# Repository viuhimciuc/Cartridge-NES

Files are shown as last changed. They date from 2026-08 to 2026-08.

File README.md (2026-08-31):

# 🎮 Nintendo Entertainment System (NES) Cartridge PCBs






An open-source collection of hardware design files and schematics for custom, functional **Nintendo Entertainment System (NES)** cartridge printed circuit boards (PCBs), using the [SST39SF010A](https://www.microchip.com/en-us/product/sst39sf010a), [SST39SF020A](https://www.microchip.com/en-us/product/sst39sf020a), [SST39SF040](https://www.microchip.com/en-us/product/sst39sf040) memory chip. This repository includes boards based on original discrete logic designs, advanced memory management controllers (MMCs), and mask ROM replacement utilities created inside **KiCad**.

---

## 📂 Repository Structure

The project organizes board designs by memory mapper architectures and utility profiles:

*   **📁 `Discrete logic boards using`** – Simple mapper solutions utilizing standard 74-series logic chips (e.g., AxROM, UxROM, NROM configurations).
*   **📁 `MMC1 boards NES-SxROM`** – Designs compatible with the Nintendo **MMC1** ASIC mapper family supporting multi-directional scrolling and battery-backed saves.
*   **📁 `MMC3 boards NES-TxROM`** – Performance configurations adapting the highly versatile **MMC3** ASIC architecture for scanline IRQ counters and larger ROM sizes.
*   **📁 `NES MASK ROM`** – Hardware breakout and adapter boards targeting pin-compatible conversions from modern Flash/EPROM/EEPROM chips to original NES hardware slots.
*   **📊 Documentation Assets:**
    *   `Mappers.xls` – Comparison matrices tracking hardware compatibility, signaling, and line configurations.
    *   `pin_MMC3.xls` – Precision mapping registers and Pinout details targeting the MMC3 layout.

---

## 📸 PCB Gallery

<p align="center">
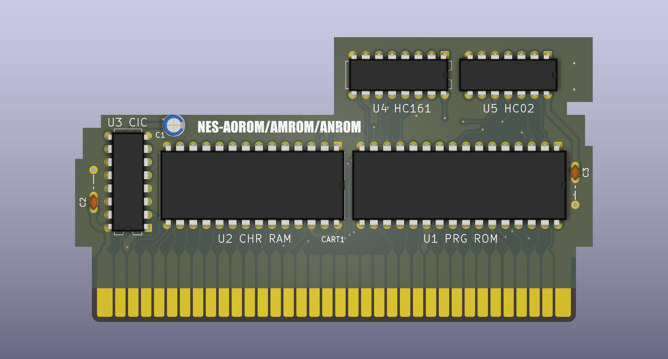
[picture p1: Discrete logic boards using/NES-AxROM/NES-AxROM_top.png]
AxROM
  
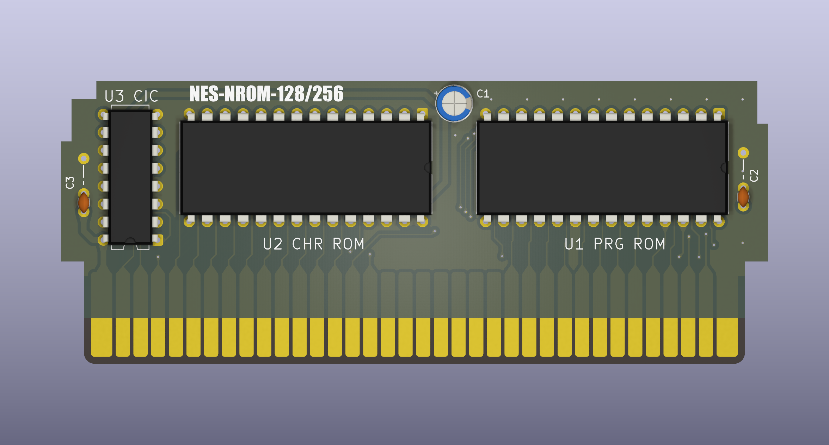
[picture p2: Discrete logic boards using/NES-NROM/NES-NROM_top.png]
NROM
  
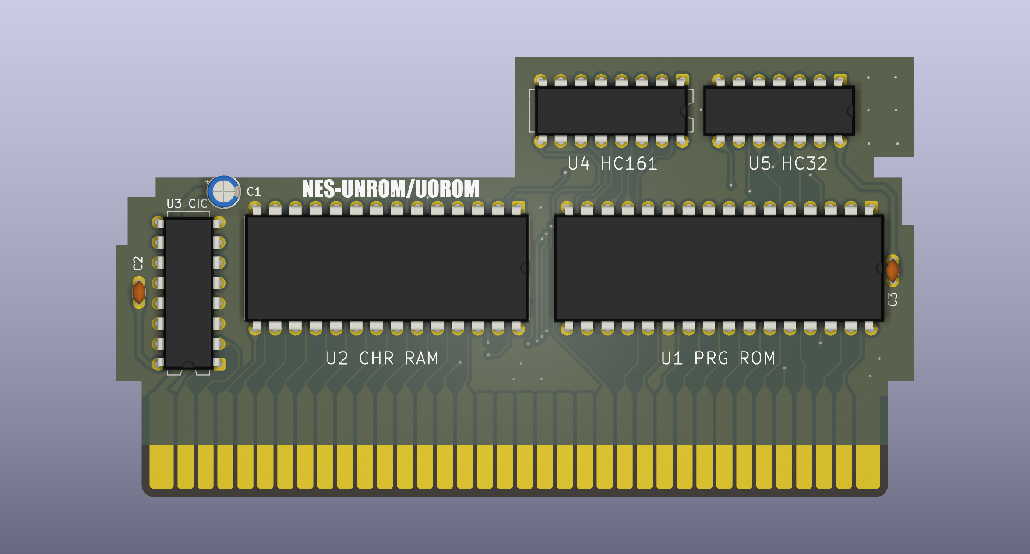
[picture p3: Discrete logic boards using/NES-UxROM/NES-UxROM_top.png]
UxROM
  
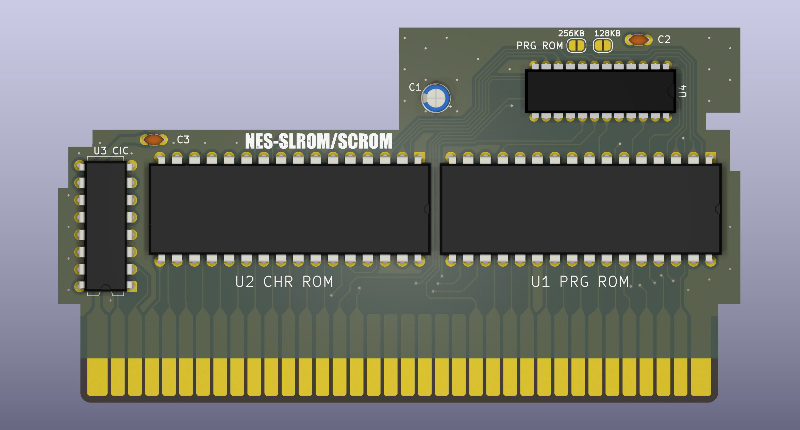
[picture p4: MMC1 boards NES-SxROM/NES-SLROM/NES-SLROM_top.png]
MMC1 SLROM Board
  
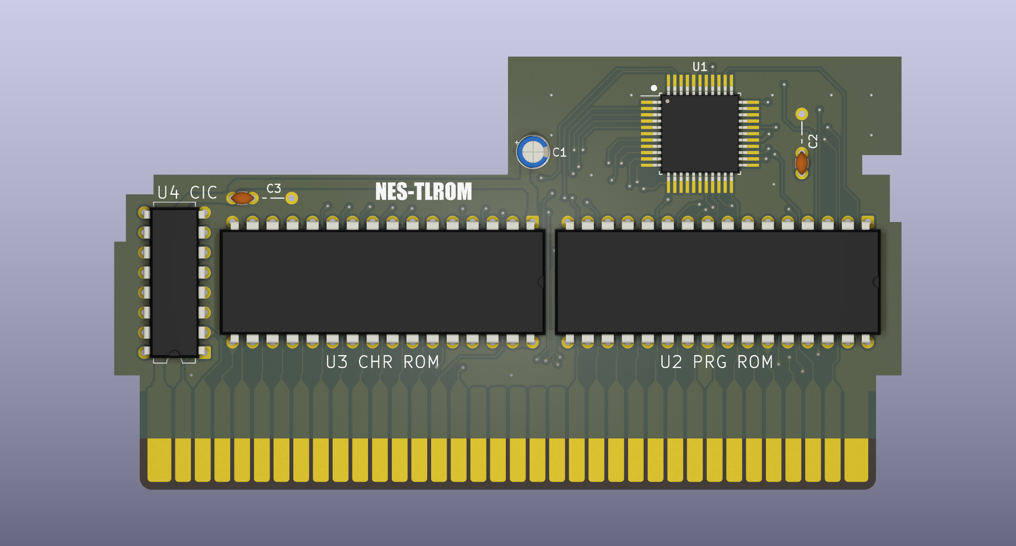
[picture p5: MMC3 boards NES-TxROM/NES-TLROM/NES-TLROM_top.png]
MMC3 TLROM Board
  
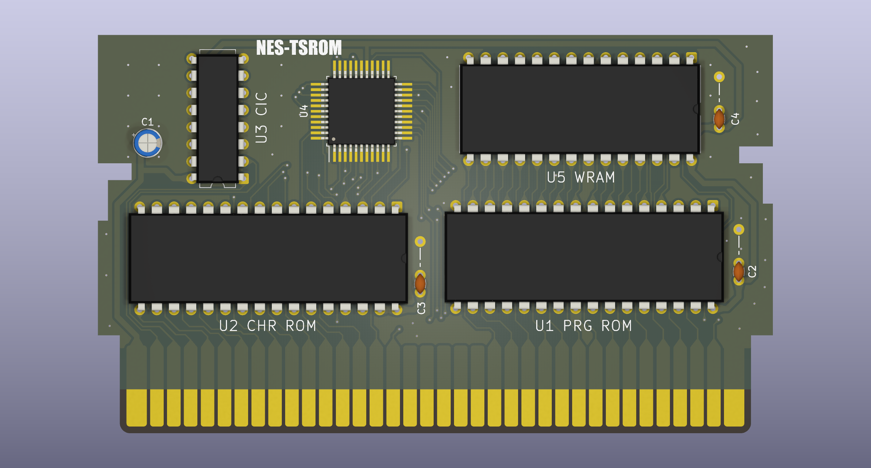
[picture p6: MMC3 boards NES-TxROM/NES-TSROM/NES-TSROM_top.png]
MMC3 TSROM Board
  
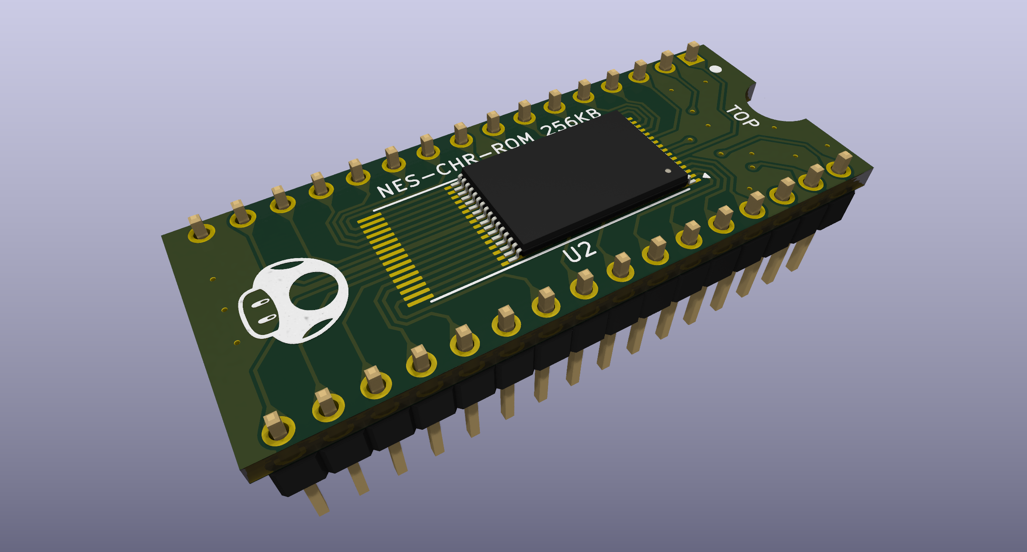
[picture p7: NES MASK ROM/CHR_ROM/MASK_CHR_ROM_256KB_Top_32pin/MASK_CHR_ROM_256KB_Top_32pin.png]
MASK CHR-ROM 256KB
  
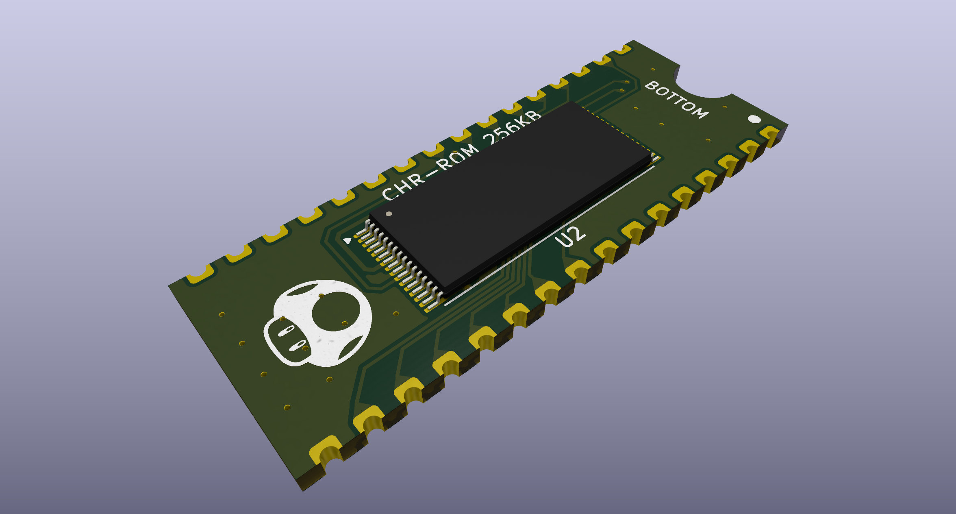
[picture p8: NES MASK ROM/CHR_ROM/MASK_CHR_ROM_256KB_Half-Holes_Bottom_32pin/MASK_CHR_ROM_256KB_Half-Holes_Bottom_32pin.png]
MASK CHR-ROM Half-Holes 256KB
  
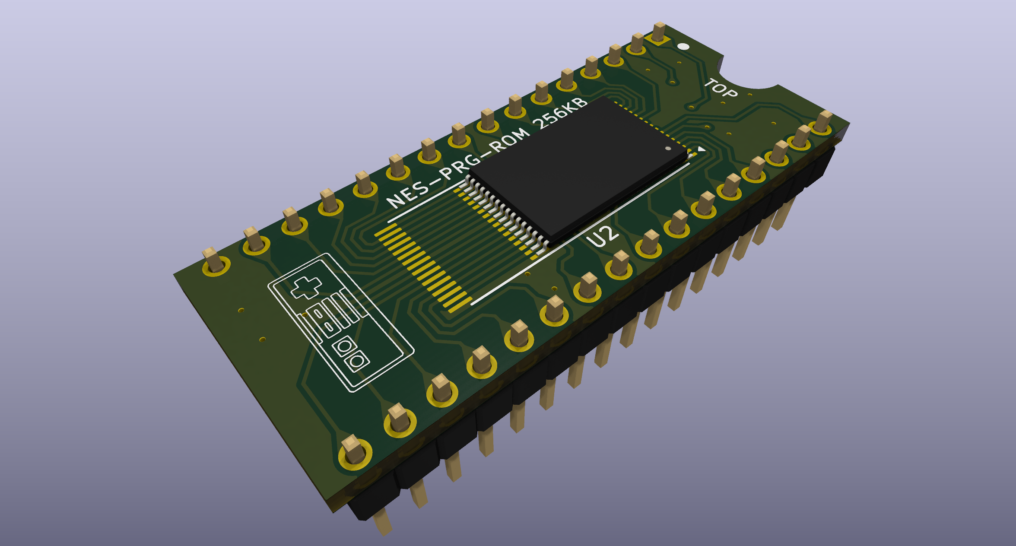
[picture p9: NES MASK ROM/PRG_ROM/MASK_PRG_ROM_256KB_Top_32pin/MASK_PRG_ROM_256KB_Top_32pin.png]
MASK PRG-ROM 256KB
  
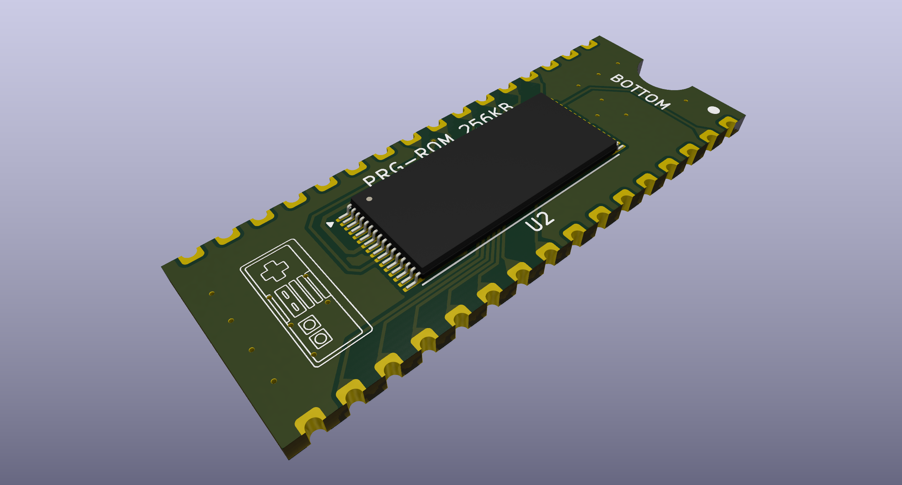
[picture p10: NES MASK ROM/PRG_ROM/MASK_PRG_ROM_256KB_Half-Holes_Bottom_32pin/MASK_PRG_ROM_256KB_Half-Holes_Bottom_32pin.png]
MASK PRG-ROM Half-Holes 256KB
  
</p>

---

## 🛠️ Getting Started & Manufacturing

### Prerequisites
1. Download and set up the stable branch of [KiCad EDA](https://kicad.org/).
2. Standard interactive hardware tools (soldering iron, multi-meter, flux).

### Cloning the Project
```bash
git clone https://github.com/viuhimciuc/Cartridge-NES.git
cd Cartridge-NES
```

### Exporting Gerbers for PCB Production
1. Launch **KiCad** and open the `.kicad_pcb` layout file from the directory matching your board configuration.
2. Navigate to **File** ➡️ **Plot...**
3. Select **Gerber** as the output configuration format.
4. Specify target layers (typically *F.Cu*, *B.Cu*, *F.Paste*, *B.Paste*, *F.Silkscreen*, *B.Silkscreen*, *F.Mask*, *B.Mask*, and *Edge.Cuts*).
5. Choose **Generate Drill Files...** using standard Exxon/Drill configurations.
6. Package all generated artifacts into a single `.zip` archive.
7. Upload the container directly to production fabs like [JLCPCB](https://jlcpcb.com/) or [PCBWay](https://www.pcbway.com/).

---

## 🤝 Contributing & Support

Contributions addressing trace corrections, optimized routing patterns, or alternative flash memory compatibility layouts are welcome! 

1. **Fork** this repository.
2. Build an active feature/fix branch (`git checkout -b feature/AmazingFeature`).
3. Commit structural modifications (`git commit -m 'Add support for unique flash footprints'`).
4. **Push** the configuration branch (`git push origin feature/AmazingFeature`).
5. Open a **Pull Request**.

---

## 📜 License

Distributed under the **MIT License**. Check out the accompanying `.gitignore` configuration for setup parameters.

---
<p align="center">Made with ❤️ for retro console preservation.</p>

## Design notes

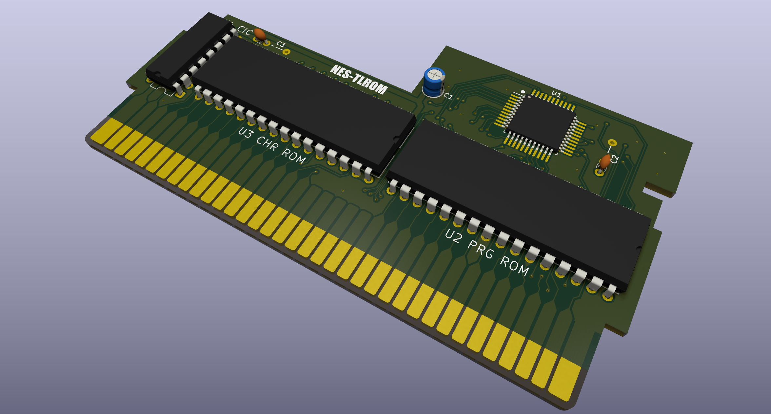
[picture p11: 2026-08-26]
MMC3 boards NES-TxROM/NES-TLROM/NES-TLROM.png

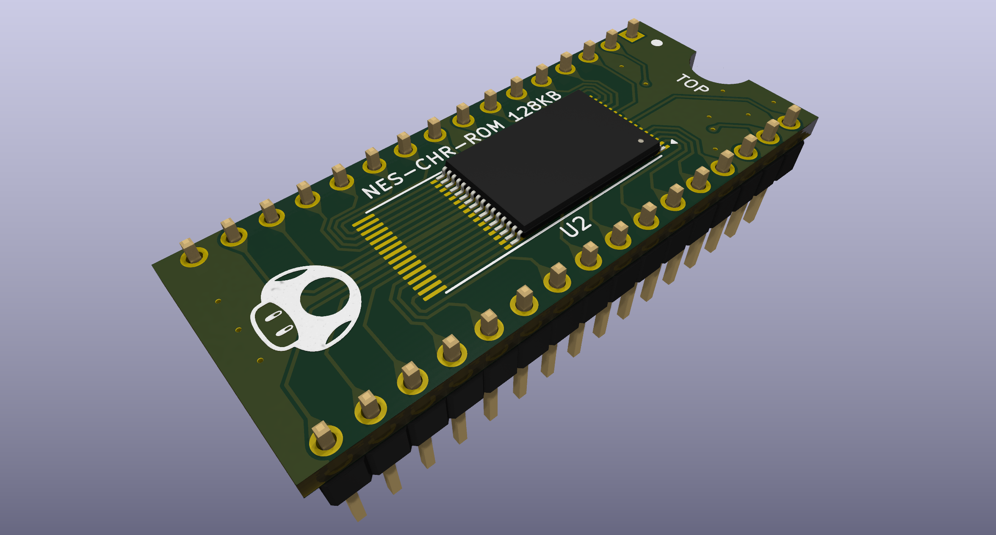
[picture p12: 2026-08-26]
NES MASK ROM/CHR_ROM/MASK_CHR_ROM_128KB_Top_32pin/MASK_CHR_ROM_128KB_Top_32pin.png

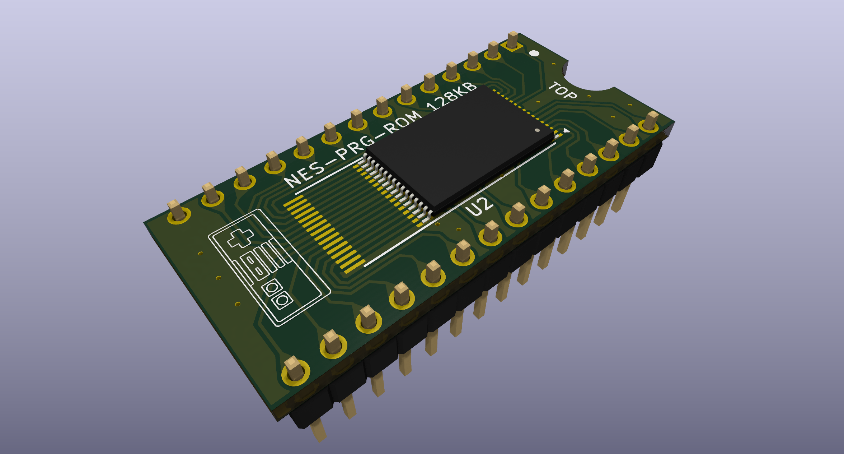
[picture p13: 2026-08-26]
NES MASK ROM/PRG_ROM/MASK_PRG_ROM_128KB_Top_28pin/MASK_PRG_ROM_128KB_Top_28pin.png

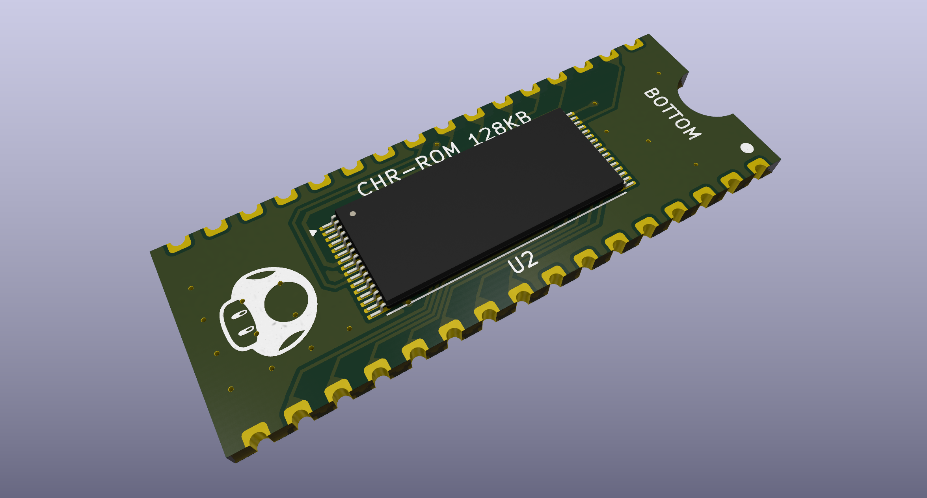
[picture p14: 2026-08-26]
NES MASK ROM/CHR_ROM/MASK_CHR_ROM_128KB_Half-Holes_Bottom_32pin/MASK_CHR_ROM_128KB_Half-Holes_Bottom_32pin.png

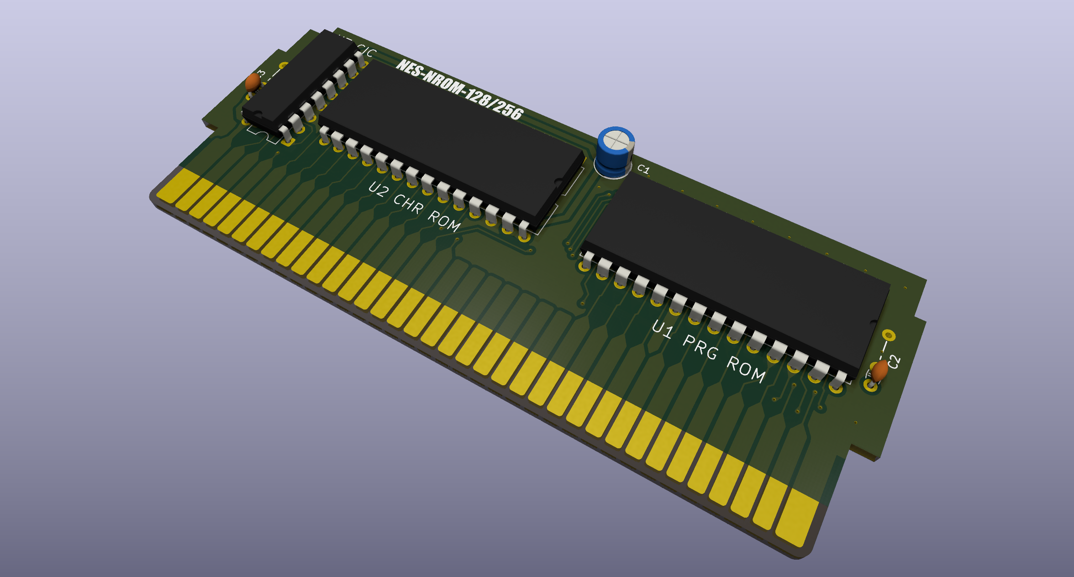
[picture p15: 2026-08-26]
Discrete logic boards using/NES-NROM/NES-NROM.png

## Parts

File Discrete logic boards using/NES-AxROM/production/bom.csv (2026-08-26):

Designator | Footprint | Quantity | Value | LCSC Part #
C1 | CP_Radial_D4.0mm_P2.00mm | 1 | 22uF
C2, C3 | C_Axial_P7.5mm_P2.50mm | 2 | 0.1uF
CART1 | PCB_4-CART-72-2.50-CONN | 1 | EDGE-CONN-72-PIN-PCB_4
JP1 | SolderJumper-3_P1.3mm_Open_RoundedPad1.0x1.5mm_NumberLabels | 1 | A17
JP2 | SolderJumper-3_P1.3mm_Open_RoundedPad1.0x1.5mm_NumberLabels | 1 | OE
JP3 | SolderJumper-3_P1.3mm_Open_RoundedPad1.0x1.5mm_NumberLabels | 1 | D2
U1 | DIP-32_W15.24mm | 1 | SST39SF020
U2 | DIP-28_W15.24mm | 1 | HM6264ALP
U3 | DIP-16_W7.62mm | 1 | 6113B1
U4 | DIP-16_W7.62mm | 1 | 74LS161
U5 | DIP-14_W7.62mm | 1 | 74HC02

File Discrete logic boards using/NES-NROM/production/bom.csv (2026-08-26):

Designator | Footprint | Quantity | Value | LCSC Part #
C1 | CP_Radial_D5.0mm_P2.50mm | 1 | 22uF
C2, C3 | C_Axial_P7.5mm_P2.50mm | 2 | 0.1uF
CART1 | PCB_5-CART-72-2.50-CONN | 1 | EDGE-CONN-72-PIN-PCB_5
JP1, JP2 | SolderJumper-3_P1.3mm_Open_RoundedPad1.0x1.5mm_NumberLabels | 2 | SolderJumper_3_Open
U1 | DIP-28_W15.24mm | 1 | AT28C128 / AT28C256
U2 | DIP-28_W15.24mm | 1 | AT28C64B
U3 | DIP-16_W7.62mm | 1 | 6113B1

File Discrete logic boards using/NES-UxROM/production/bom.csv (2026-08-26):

Designator | Footprint | Quantity | Value | LCSC Part #
C1 | CP_Radial_D4.0mm_P1.50mm | 1 | 22uF
C2, C3 | C_Disc_D3.0mm_W1.6mm_P2.50mm | 2 | 0.1uF
CART1 | PCB_4-CART-72-2.50-CONN | 1 | EDGE-CONN-72-PIN-PCB_4
JP3 | SolderJumper-2_P1.3mm_Open_RoundedPad1.0x1.5mm | 1 | 128KB
JP4 | SolderJumper-2_P1.3mm_Open_RoundedPad1.0x1.5mm | 1 | 256KB
U1 | DIP-32_W15.24mm | 1 | SST39SF020
U2 | DIP-28_W15.24mm | 1 | AS6C6264
U3 | DIP-16_W7.62mm | 1 | 6113B1
U4 | DIP-16_W7.62mm | 1 | 74LS161
U5 | DIP-14_W7.62mm | 1 | 74LS32

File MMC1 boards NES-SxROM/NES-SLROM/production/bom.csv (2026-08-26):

Designator | Footprint | Quantity | Value | LCSC Part #
C1 | CP_Radial_D4.0mm_P1.50mm | 1 | 22uF
C2, C3 | C_Disc_D3.0mm_W1.6mm_P2.50mm | 2 | 0.1uF
CART1 | PCB_4-CART-72-2.50-CONN | 1 | EDGE-CONN-72-PIN-PCB_4
JP1 | SolderJumper-2_P1.3mm_Open_RoundedPad1.0x1.5mm | 1 | 256KB
JP2 | SolderJumper-2_P1.3mm_Open_RoundedPad1.0x1.5mm | 1 | 128KB
U1 | DIP-32_W15.24mm | 1 | SST39SF020
U2 | DIP-32_W15.24mm | 1 | SST39SF010
U3 | DIP-16_W7.62mm | 1 | 6113B1
U4 | DIP-24_W7.62mm_Pads_1.78mm | 1 | MMC1

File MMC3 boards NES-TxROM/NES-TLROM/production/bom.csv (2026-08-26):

Designator | Footprint | Quantity | Value | LCSC Part #
C1 | CP_Radial_D4.0mm_P2.00mm | 1 | 22uF
C2, C3 | C_Axial_P7.5mm_P2.50mm | 2 | 0.1uF
CART1 | PCB_4-CART-72-2.50-CONN | 1 | EDGE-CONN-72-PIN-PCB_4
U1 | MMC3_TQFP-44 | 1 | MMC3
U2, U3 | DIP-32_W15.24mm | 2 | SST39SF020
U4 | DIP-16_W7.62mm | 1 | 6113B1

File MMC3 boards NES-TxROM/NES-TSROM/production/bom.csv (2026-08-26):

Designator | Footprint | Quantity | Value | LCSC Part #
C1 | CP_Radial_D4.0mm_P2.00mm | 1 | 22uF
C2, C3, C4 | C_Axial_P7.5mm_P2.50mm | 3 | 0.1uF
CART1 | PCB_3-CART-72-2.50-CONN | 1 | EDGE-CONN-72-PIN-PCB_3
U1, U2 | DIP-32_W15.24mm | 2 | SST39SF020
U3 | DIP-16_W7.62mm | 1 | 6113B1
U4 | MMC3_TQFP-44 | 1 | MMC3
U5 | DIP-28_W15.24mm | 1 | HM6264ALP

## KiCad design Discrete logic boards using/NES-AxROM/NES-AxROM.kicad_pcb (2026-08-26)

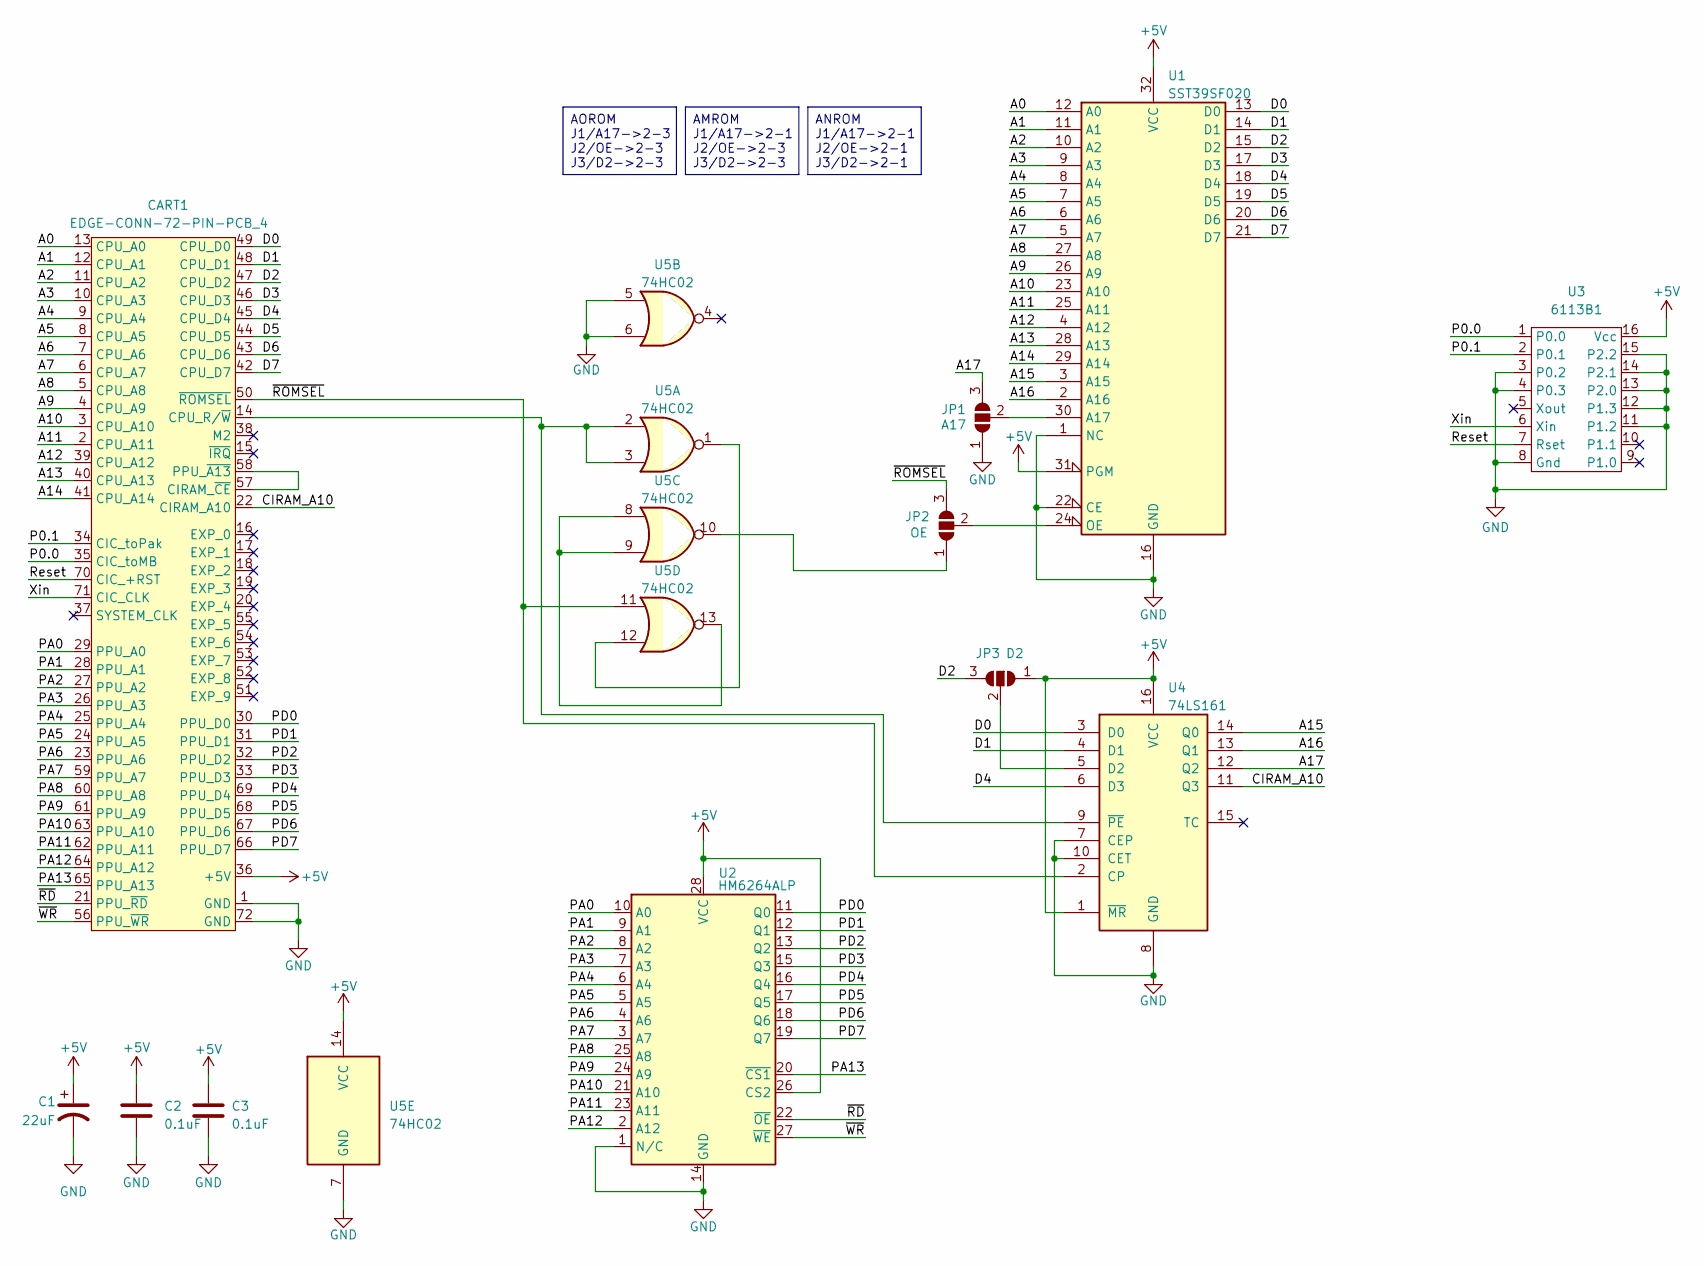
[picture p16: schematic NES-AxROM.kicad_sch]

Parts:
C1: 22uF; CP_Radial_D4.0mm_P2.00mm
C2, C3: 0.1uF; C_Axial_P7.5mm_P2.50mm
CART1: EDGE-CONN-72-PIN-PCB_4; PCB_4-CART-72-2.50-CONN
JP1: A17; SolderJumper-3_P1.3mm_Open_RoundedPad1.0x1.5mm_NumberLabels
JP2: OE; SolderJumper-3_P1.3mm_Open_RoundedPad1.0x1.5mm_NumberLabels
JP3: D2; SolderJumper-3_P1.3mm_Open_RoundedPad1.0x1.5mm_NumberLabels
U1: SST39SF020; DIP-32_W15.24mm
U2: HM6264ALP; DIP-28_W15.24mm
U3: 6113B1; DIP-16_W7.62mm
U4: 74LS161; DIP-16_W7.62mm
U5: 74HC02; DIP-14_W7.62mm

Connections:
+5V: C1.1, C2.1, C3.1, CART1.36 (+5V), JP3.1 (A), U1.31 (PGM), U1.32 (VCC), U2.26 (CS2), U2.28 (VCC), U3.16 (Vcc), U4.1 (~MR), U4.16 (VCC), U5.14 (VCC)
/A0: CART1.13 (CPU_A0), U1.12 (A0)
/A1: CART1.12 (CPU_A1), U1.11 (A1)
/A2: CART1.11 (CPU_A2), U1.10 (A2)
/A3: CART1.10 (CPU_A3), U1.9 (A3)
/A4: CART1.9 (CPU_A4), U1.8 (A4)
/A5: CART1.8 (CPU_A5), U1.7 (A5)
/A6: CART1.7 (CPU_A6), U1.6 (A6)
/A7: CART1.6 (CPU_A7), U1.5 (A7)
/A8: CART1.5 (CPU_A8), U1.27 (A8)
/A9: CART1.4 (CPU_A9), U1.26 (A9)
/A10: CART1.3 (CPU_A10), U1.23 (A10)
/A11: CART1.2 (CPU_A11), U1.25 (A11)
/A12: CART1.39 (CPU_A12), U1.4 (A12)
/A13: CART1.40 (CPU_A13), U1.28 (A13)
/A14: CART1.41 (CPU_A14), U1.29 (A14)
/A15: U1.3 (A15), U4.14 (Q0)
/A16: U1.2 (A16), U4.13 (Q1)
/A17: JP1.3 (B), U4.12 (Q2)
/CIRAM_A10: CART1.22 (CIRAM_A10), U4.11 (Q3)
/D0: CART1.49 (CPU_D0), U1.13 (D0), U4.3 (D0)
/D1: CART1.48 (CPU_D1), U1.14 (D1), U4.4 (D1)
/D2: CART1.47 (CPU_D2), JP3.3 (B), U1.15 (D2)
/D3: CART1.46 (CPU_D3), U1.17 (D3)
/D4: CART1.45 (CPU_D4), U1.18 (D4), U4.6 (D3)
/D5: CART1.44 (CPU_D5), U1.19 (D5)
/D6: CART1.43 (CPU_D6), U1.20 (D6)
/D7: CART1.42 (CPU_D7), U1.21 (D7)
/P0.0: CART1.35 (CIC_toMB), U3.1 (P0.0)
/P0.1: CART1.34 (CIC_toPak), U3.2 (P0.1)
/PA0: CART1.29 (PPU_A0), U2.10 (A0)
/PA1: CART1.28 (PPU_A1), U2.9 (A1)
/PA2: CART1.27 (PPU_A2), U2.8 (A2)
/PA3: CART1.26 (PPU_A3), U2.7 (A3)
/PA4: CART1.25 (PPU_A4), U2.6 (A4)
/PA5: CART1.24 (PPU_A5), U2.5 (A5)
/PA6: CART1.23 (PPU_A6), U2.4 (A6)
/PA7: CART1.59 (PPU_A7), U2.3 (A7)
/PA8: CART1.60 (PPU_A8), U2.25 (A8)
/PA9: CART1.61 (PPU_A9), U2.24 (A9)
/PA10: CART1.63 (PPU_A10), U2.21 (A10)
/PA11: CART1.62 (PPU_A11), U2.23 (A11)
/PA12: CART1.64 (PPU_A12), U2.2 (A12)
/PA13: CART1.65 (PPU_A13), U2.20 (~CS1)
/PD0: CART1.30 (PPU_D0), U2.11 (Q0)
/PD1: CART1.31 (PPU_D1), U2.12 (Q1)
/PD2: CART1.32 (PPU_D2), U2.13 (Q2)
/PD3: CART1.33 (PPU_D3), U2.15 (Q3)
/PD4: CART1.69 (PPU_D4), U2.16 (Q4)
/PD5: CART1.68 (PPU_D5), U2.17 (Q5)
/PD6: CART1.67 (PPU_D6), U2.18 (Q6)
/PD7: CART1.66 (PPU_D7), U2.19 (Q7)
/Reset: CART1.70 (CIC_+RST), U3.7 (Rset)
/Xin: CART1.71 (CIC_CLK), U3.6 (Xin)
/~RD: CART1.21 (PPU_~RD), U2.22 (~OE)
/~ROMSEL: CART1.50 (~ROMSEL), JP2.3 (B), U4.2 (CP), U5.11
/~WR: CART1.56 (PPU_~WR), U2.27 (~WE)
GND: C1.2, C2.2, C3.2, CART1.1 (GND), CART1.72 (GND), JP1.1 (A), U1.1 (NC), U1.16 (GND), U1.22 (CE), U2.1 (N/C), U2.14 (GND), U3.3 (P0.2), U3.4 (P0.3), U3.8 (Gnd), U3.11 (P1.2), U3.12 (P1.3), U3.13 (P2.0), U3.14 (P2.1), U3.15 (P2.2), U4.7 (CEP), U4.8 (GND), U4.10 (CET), U5.5, U5.6, U5.7 (GND)
unnamed: CART1.57 (CIRAM_~CE), CART1.58 (PPU_~A13)
unnamed: CART1.14 (CPU_R/~W), U4.9 (~PE), U5.2, U5.3
unnamed: JP1.2 (C), U1.30 (A17)
unnamed: JP2.1 (A), U5.10
unnamed: JP2.2 (C), U1.24 (OE)
unnamed: JP3.2 (C), U4.5 (D2)
unnamed: U5.1, U5.12
unnamed: U5.8, U5.9, U5.13

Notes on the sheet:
AMROM J1/A17->2-1 J2/OE->2-3 J3/D2->2-3
ANROM J1/A17->2-1 J2/OE->2-1 J3/D2->2-1
AOROM J1/A17->2-3 J2/OE->2-3 J3/D2->2-3

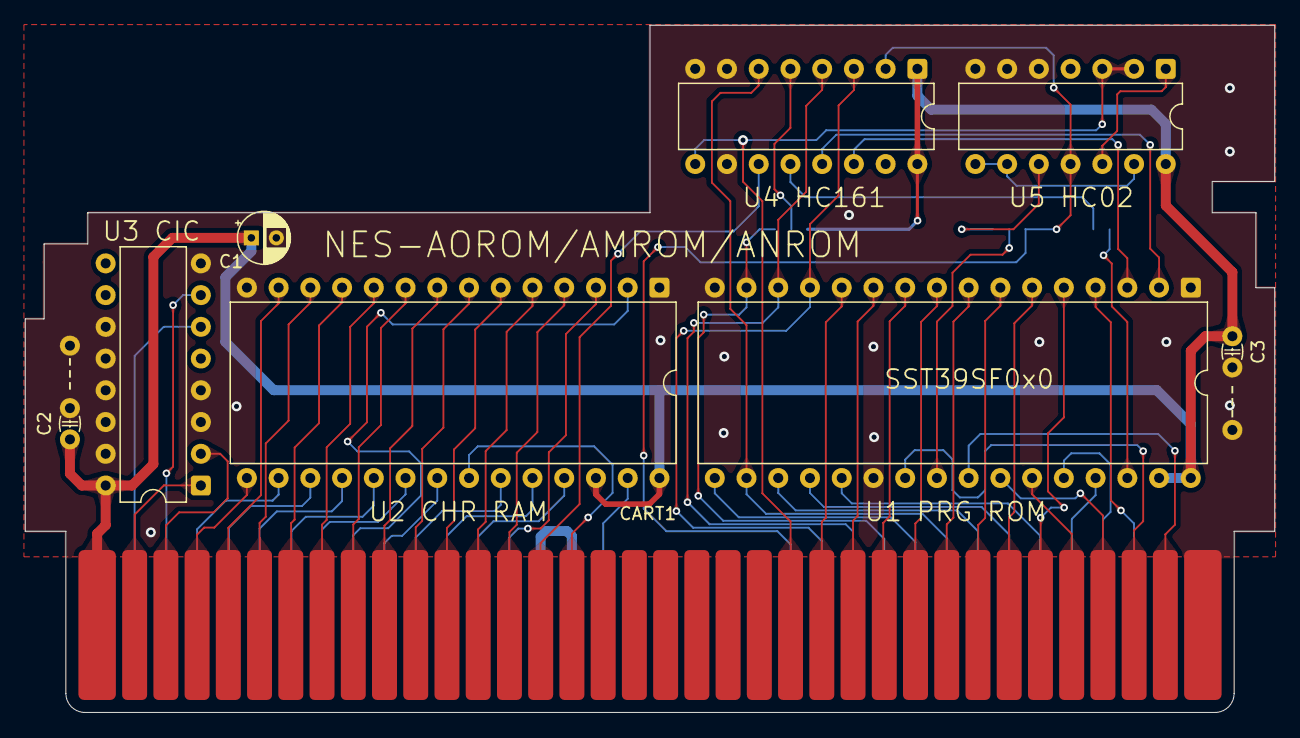
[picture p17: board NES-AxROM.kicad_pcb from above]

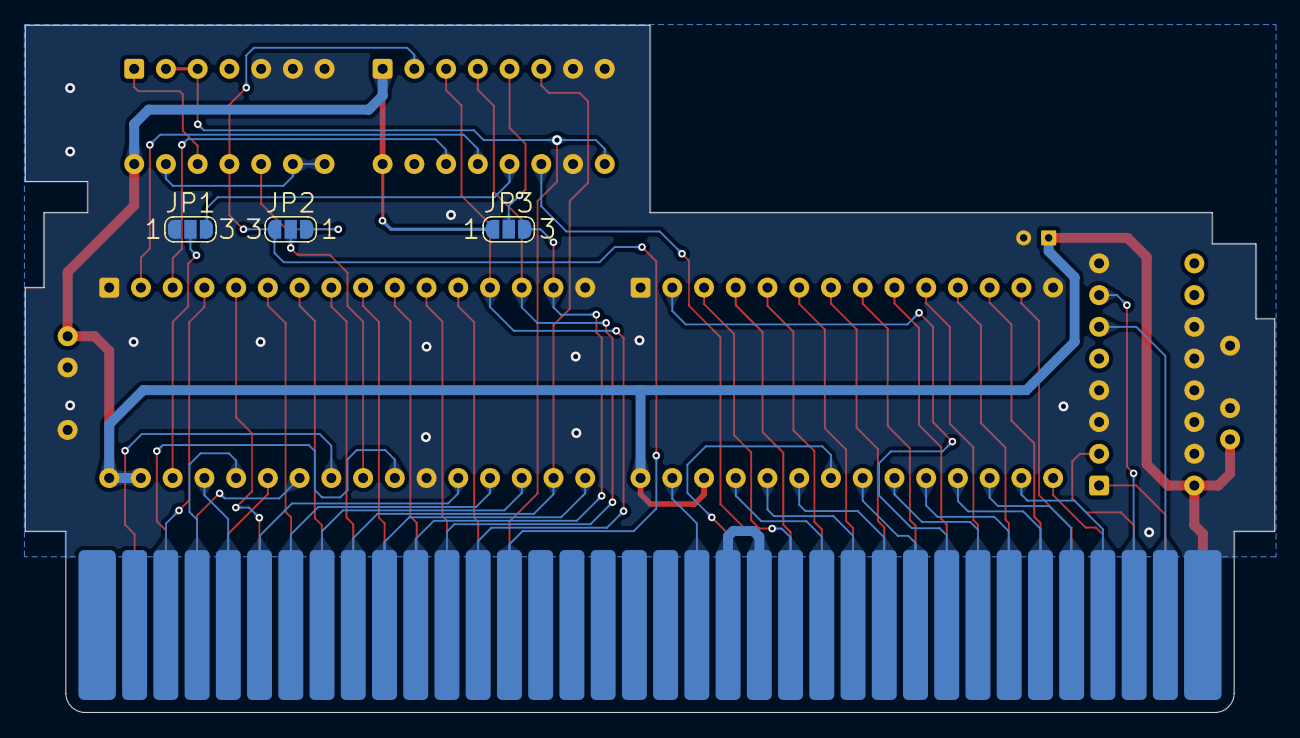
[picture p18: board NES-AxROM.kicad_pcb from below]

Board: 2 copper layers, 100.0 x 55.0 mm, 12 parts (3 on the bottom side), 66 nets.

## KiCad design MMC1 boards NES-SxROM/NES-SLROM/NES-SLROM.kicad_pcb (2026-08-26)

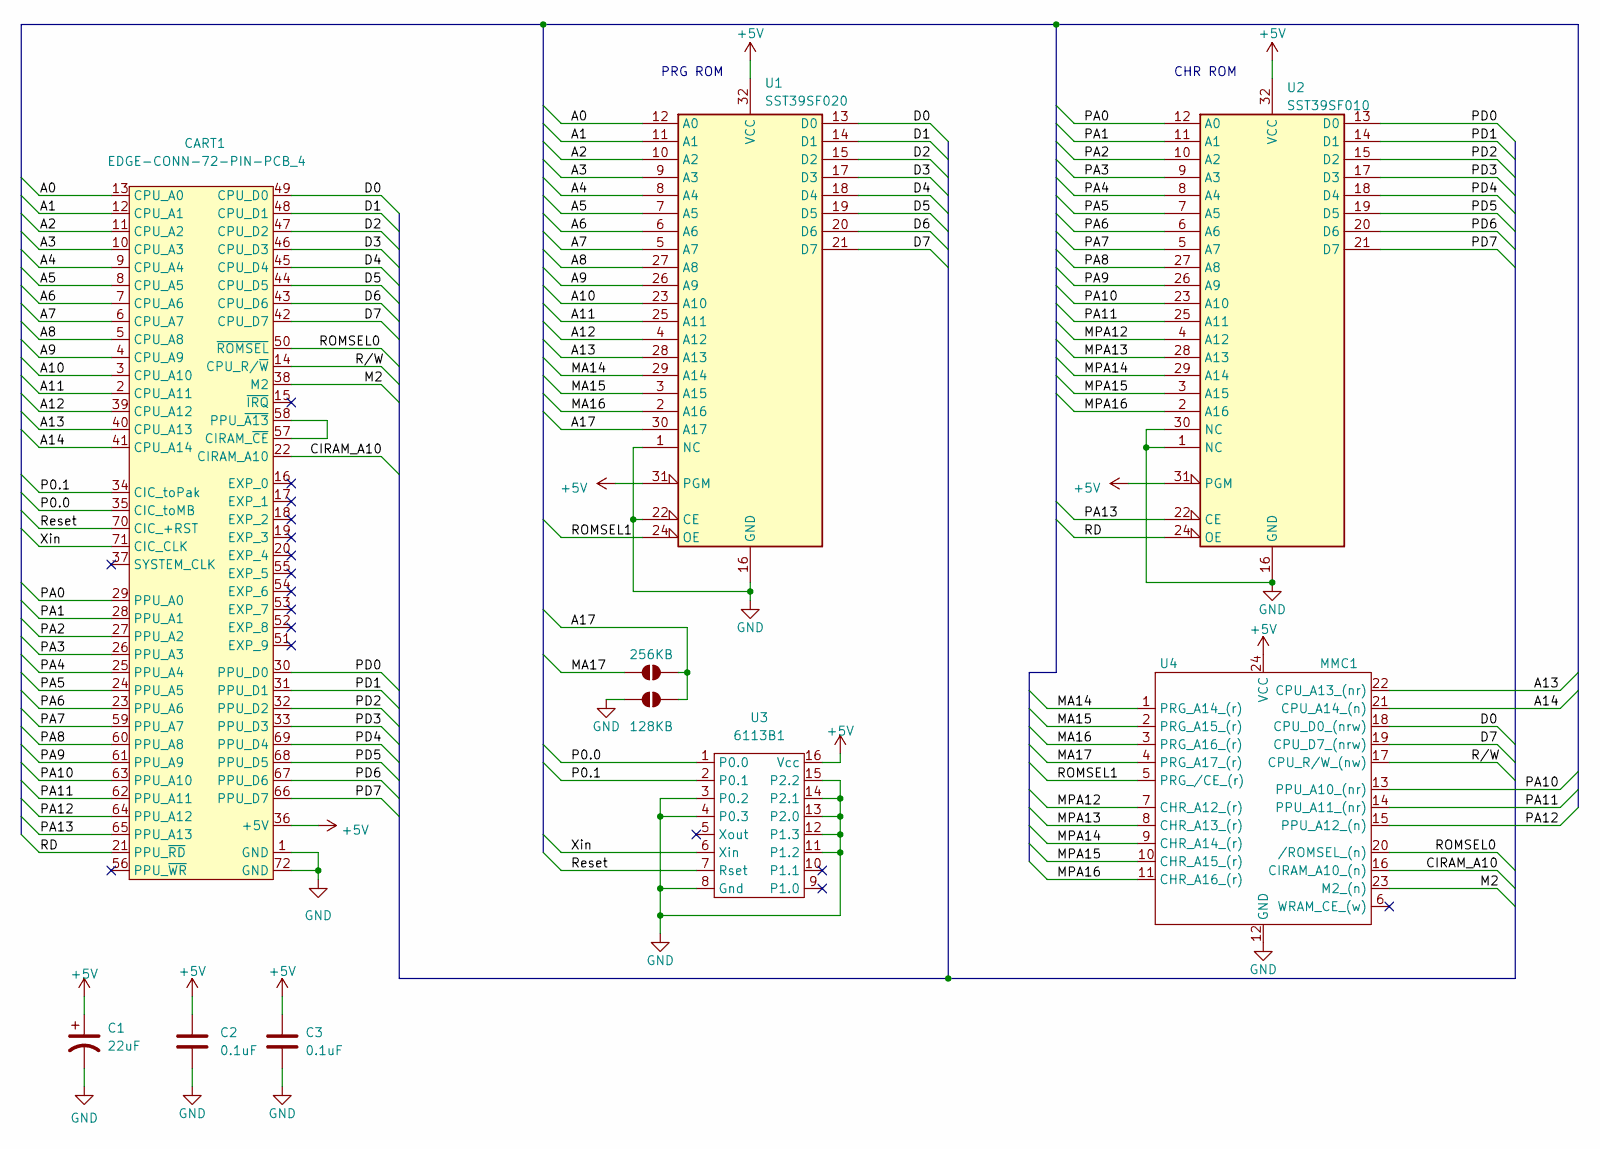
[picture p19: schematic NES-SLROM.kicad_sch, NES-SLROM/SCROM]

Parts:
C1: 22uF; CP_Radial_D4.0mm_P1.50mm
C2, C3: 0.1uF; C_Disc_D3.0mm_W1.6mm_P2.50mm
CART1: EDGE-CONN-72-PIN-PCB_4; PCB_4-CART-72-2.50-CONN
JP1: 256KB; SolderJumper-2_P1.3mm_Open_RoundedPad1.0x1.5mm
JP2: 128KB; SolderJumper-2_P1.3mm_Open_RoundedPad1.0x1.5mm
U1: SST39SF020; DIP-32_W15.24mm
U2: SST39SF010; DIP-32_W15.24mm
U3: 6113B1; DIP-16_W7.62mm
U4: MMC1; DIP-24_W7.62mm_Pads_1.78mm

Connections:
+5V: C1.1, C2.1, C3.1, CART1.36 (+5V), U1.31 (PGM), U1.32 (VCC), U2.31 (PGM), U2.32 (VCC), U3.16 (Vcc), U4.24 (VCC)
/A0: CART1.13 (CPU_A0), U1.12 (A0)
/A1: CART1.12 (CPU_A1), U1.11 (A1)
/A2: CART1.11 (CPU_A2), U1.10 (A2)
/A3: CART1.10 (CPU_A3), U1.9 (A3)
/A4: CART1.9 (CPU_A4), U1.8 (A4)
/A5: CART1.8 (CPU_A5), U1.7 (A5)
/A6: CART1.7 (CPU_A6), U1.6 (A6)
/A7: CART1.6 (CPU_A7), U1.5 (A7)
/A8: CART1.5 (CPU_A8), U1.27 (A8)
/A9: CART1.4 (CPU_A9), U1.26 (A9)
/A10: CART1.3 (CPU_A10), U1.23 (A10)
/A11: CART1.2 (CPU_A11), U1.25 (A11)
/A12: CART1.39 (CPU_A12), U1.4 (A12)
/A13: CART1.40 (CPU_A13), U1.28 (A13), U4.22 (CPU_A13_(nr))
/A14: CART1.41 (CPU_A14), U4.21 (CPU_A14_(n))
/A17: JP1.1 (A), JP2.1 (A), U1.30 (A17)
/CIRAM_A10: CART1.22 (CIRAM_A10), U4.16 (CIRAM_A10_(n))
/D0: CART1.49 (CPU_D0), U1.13 (D0), U4.18 (CPU_D0_(nrw))
/D1: CART1.48 (CPU_D1), U1.14 (D1)
/D2: CART1.47 (CPU_D2), U1.15 (D2)
/D3: CART1.46 (CPU_D3), U1.17 (D3)
/D4: CART1.45 (CPU_D4), U1.18 (D4)
/D5: CART1.44 (CPU_D5), U1.19 (D5)
/D6: CART1.43 (CPU_D6), U1.20 (D6)
/D7: CART1.42 (CPU_D7), U1.21 (D7), U4.19 (CPU_D7_(nrw))
/M2: CART1.38 (M2), U4.23 (M2_(n))
/MA14: U1.29 (A14), U4.1 (PRG_A14_(r))
/MA15: U1.3 (A15), U4.2 (PRG_A15_(r))
/MA16: U1.2 (A16), U4.3 (PRG_A16_(r))
/MA17: JP1.2 (B), U4.4 (PRG_A17_(r))
/MPA12: U2.4 (A12), U4.7 (CHR_A12_(r))
/MPA13: U2.28 (A13), U4.8 (CHR_A13_(r))
/MPA14: U2.29 (A14), U4.9 (CHR_A14_(r))
/MPA15: U2.3 (A15), U4.10 (CHR_A15_(r))
/MPA16: U2.2 (A16), U4.11 (CHR_A16_(r))
/P0.0: CART1.35 (CIC_toMB), U3.1 (P0.0)
/P0.1: CART1.34 (CIC_toPak), U3.2 (P0.1)
/PA0: CART1.29 (PPU_A0), U2.12 (A0)
/PA1: CART1.28 (PPU_A1), U2.11 (A1)
/PA2: CART1.27 (PPU_A2), U2.10 (A2)
/PA3: CART1.26 (PPU_A3), U2.9 (A3)
/PA4: CART1.25 (PPU_A4), U2.8 (A4)
/PA5: CART1.24 (PPU_A5), U2.7 (A5)
/PA6: CART1.23 (PPU_A6), U2.6 (A6)
/PA7: CART1.59 (PPU_A7), U2.5 (A7)
/PA8: CART1.60 (PPU_A8), U2.27 (A8)
/PA9: CART1.61 (PPU_A9), U2.26 (A9)
/PA10: CART1.63 (PPU_A10), U2.23 (A10), U4.13 (PPU_A10_(nr))
/PA11: CART1.62 (PPU_A11), U2.25 (A11), U4.14 (PPU_A11_(nr))
/PA12: CART1.64 (PPU_A12), U4.15 (PPU_A12_(n))
/PA13: CART1.65 (PPU_A13), U2.22 (CE)
/PD0: CART1.30 (PPU_D0), U2.13 (D0)
/PD1: CART1.31 (PPU_D1), U2.14 (D1)
/PD2: CART1.32 (PPU_D2), U2.15 (D2)
/PD3: CART1.33 (PPU_D3), U2.17 (D3)
/PD4: CART1.69 (PPU_D4), U2.18 (D4)
/PD5: CART1.68 (PPU_D5), U2.19 (D5)
/PD6: CART1.67 (PPU_D6), U2.20 (D6)
/PD7: CART1.66 (PPU_D7), U2.21 (D7)
/RD: CART1.21 (PPU_~RD), U2.24 (OE)
/ROMSEL0: CART1.50 (~ROMSEL), U4.20 (/ROMSEL_(n))
/ROMSEL1: U1.24 (OE), U4.5 (PRG_/CE_(r))
/Reset: CART1.70 (CIC_+RST), U3.7 (Rset)
/R/W: CART1.14 (CPU_R/~W), U4.17 (CPU_R/W_(nw))
/Xin: CART1.71 (CIC_CLK), U3.6 (Xin)
GND: C1.2, C2.2, C3.2, CART1.1 (GND), CART1.72 (GND), JP2.2 (B), U1.1 (NC), U1.16 (GND), U1.22 (CE), U2.1 (NC), U2.16 (GND), U2.30 (NC), U3.3 (P0.2), U3.4 (P0.3), U3.8 (Gnd), U3.11 (P1.2), U3.12 (P1.3), U3.13 (P2.0), U3.14 (P2.1), U3.15 (P2.2), U4.12 (GND)
unnamed: CART1.57 (CIRAM_~CE), CART1.58 (PPU_~A13)

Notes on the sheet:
PRG ROM
CHR ROM

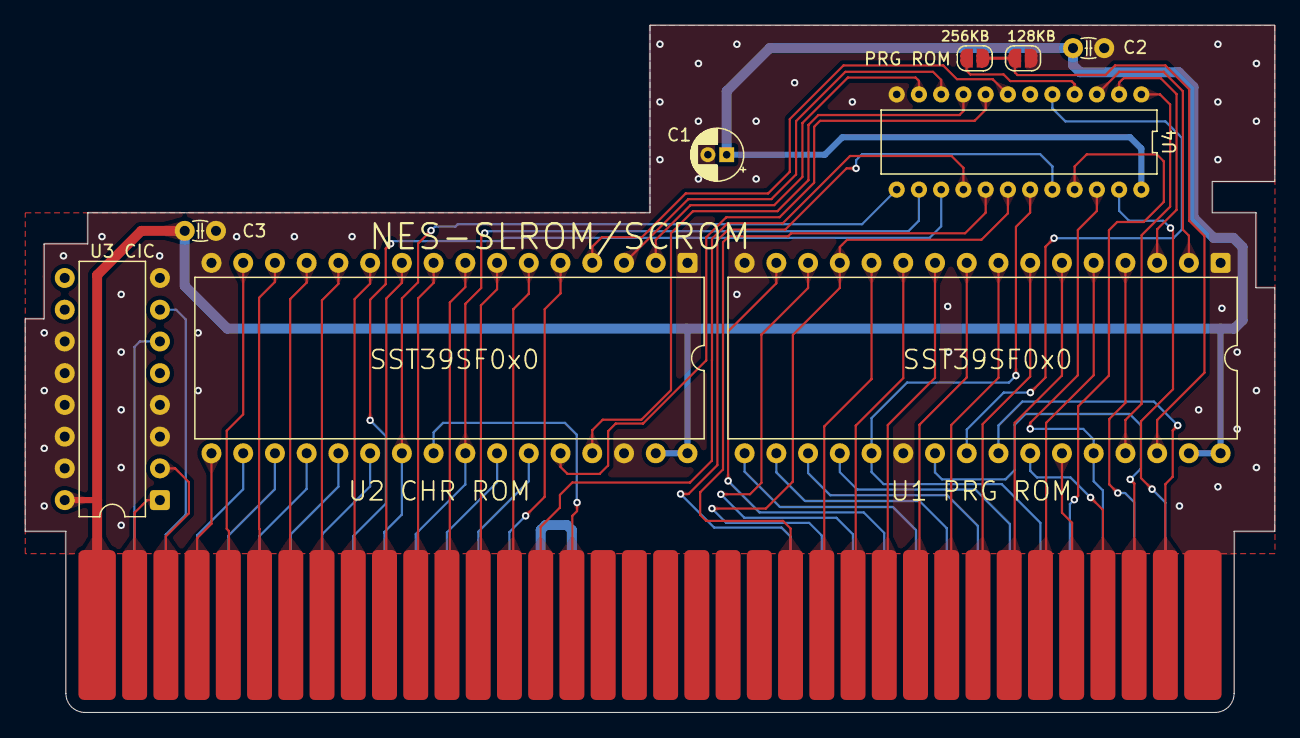
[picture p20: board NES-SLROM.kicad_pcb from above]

Board: 2 copper layers, 100.0 x 55.0 mm, 10 parts (0 on the bottom side), 68 nets.

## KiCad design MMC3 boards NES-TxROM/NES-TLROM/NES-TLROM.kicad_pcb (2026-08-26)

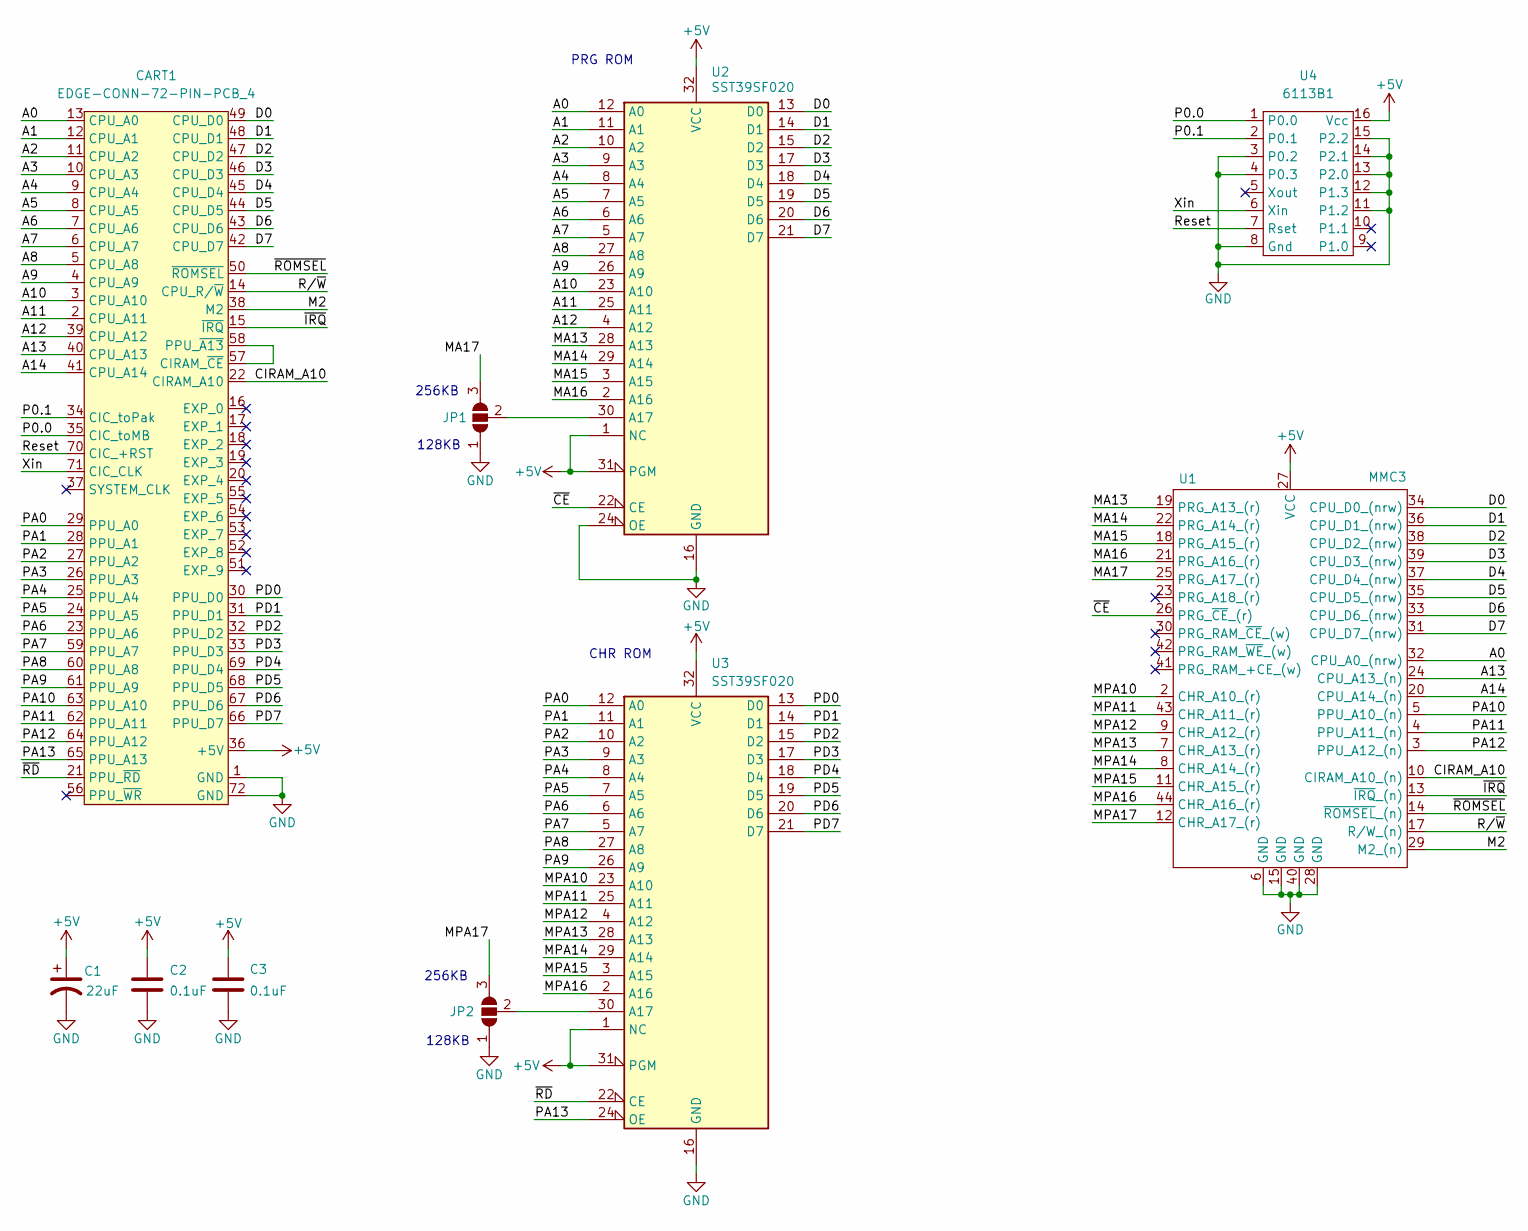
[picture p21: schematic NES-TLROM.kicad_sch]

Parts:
C1: 22uF; CP_Radial_D4.0mm_P2.00mm
C2, C3: 0.1uF; C_Axial_P7.5mm_P2.50mm
CART1: EDGE-CONN-72-PIN-PCB_4; PCB_4-CART-72-2.50-CONN
JP1, JP2: SolderJumper_3_Open; SolderJumper-3_P1.3mm_Open_RoundedPad1.0x1.5mm_NumberLabels
U1: MMC3; MMC3_TQFP-44
U2, U3: SST39SF020; DIP-32_W15.24mm
U4: 6113B1; DIP-16_W7.62mm

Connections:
+5V: C1.1, C2.1, C3.1, CART1.36 (+5V), U1.27 (VCC), U2.1 (NC), U2.31 (PGM), U2.32 (VCC), U3.1 (NC), U3.31 (PGM), U3.32 (VCC), U4.16 (Vcc)
/A0: CART1.13 (CPU_A0), U1.32 (CPU_A0_(nrw)), U2.12 (A0)
/A1: CART1.12 (CPU_A1), U2.11 (A1)
/A2: CART1.11 (CPU_A2), U2.10 (A2)
/A3: CART1.10 (CPU_A3), U2.9 (A3)
/A4: CART1.9 (CPU_A4), U2.8 (A4)
/A5: CART1.8 (CPU_A5), U2.7 (A5)
/A6: CART1.7 (CPU_A6), U2.6 (A6)
/A7: CART1.6 (CPU_A7), U2.5 (A7)
/A8: CART1.5 (CPU_A8), U2.27 (A8)
/A9: CART1.4 (CPU_A9), U2.26 (A9)
/A10: CART1.3 (CPU_A10), U2.23 (A10)
/A11: CART1.2 (CPU_A11), U2.25 (A11)
/A12: CART1.39 (CPU_A12), U2.4 (A12)
/A13: CART1.40 (CPU_A13), U1.24 (CPU_A13_(n))
/A14: CART1.41 (CPU_A14), U1.20 (CPU_A14_(n))
/CIRAM_A10: CART1.22 (CIRAM_A10), U1.10 (CIRAM_A10_(n))
/D0: CART1.49 (CPU_D0), U1.34 (CPU_D0_(nrw)), U2.13 (D0)
/D1: CART1.48 (CPU_D1), U1.36 (CPU_D1_(nrw)), U2.14 (D1)
/D2: CART1.47 (CPU_D2), U1.38 (CPU_D2_(nrw)), U2.15 (D2)
/D3: CART1.46 (CPU_D3), U1.39 (CPU_D3_(nrw)), U2.17 (D3)
/D4: CART1.45 (CPU_D4), U1.37 (CPU_D4_(nrw)), U2.18 (D4)
/D5: CART1.44 (CPU_D5), U1.35 (CPU_D5_(nrw)), U2.19 (D5)
/D6: CART1.43 (CPU_D6), U1.33 (CPU_D6_(nrw)), U2.20 (D6)
/D7: CART1.42 (CPU_D7), U1.31 (CPU_D7_(nrw)), U2.21 (D7)
/M2: CART1.38 (M2), U1.29 (M2_(n))
/MA13: U1.19 (PRG_A13_(r)), U2.28 (A13)
/MA14: U1.22 (PRG_A14_(r)), U2.29 (A14)
/MA15: U1.18 (PRG_A15_(r)), U2.3 (A15)
/MA16: U1.21 (PRG_A16_(r)), U2.2 (A16)
/MA17: JP1.3 (B), U1.25 (PRG_A17_(r))
/MPA10: U1.2 (CHR_A10_(r)), U3.23 (A10)
/MPA11: U1.43 (CHR_A11_(r)), U3.25 (A11)
/MPA12: U1.9 (CHR_A12_(r)), U3.4 (A12)
/MPA13: U1.7 (CHR_A13_(r)), U3.28 (A13)
/MPA14: U1.8 (CHR_A14_(r)), U3.29 (A14)
/MPA15: U1.11 (CHR_A15_(r)), U3.3 (A15)
/MPA16: U1.44 (CHR_A16_(r)), U3.2 (A16)
/MPA17: JP2.3 (B), U1.12 (CHR_A17_(r))
/P0.0: CART1.35 (CIC_toMB), U4.1 (P0.0)
/P0.1: CART1.34 (CIC_toPak), U4.2 (P0.1)
/PA0: CART1.29 (PPU_A0), U3.12 (A0)
/PA1: CART1.28 (PPU_A1), U3.11 (A1)
/PA2: CART1.27 (PPU_A2), U3.10 (A2)
/PA3: CART1.26 (PPU_A3), U3.9 (A3)
/PA4: CART1.25 (PPU_A4), U3.8 (A4)
/PA5: CART1.24 (PPU_A5), U3.7 (A5)
/PA6: CART1.23 (PPU_A6), U3.6 (A6)
/PA7: CART1.59 (PPU_A7), U3.5 (A7)
/PA8: CART1.60 (PPU_A8), U3.27 (A8)
/PA9: CART1.61 (PPU_A9), U3.26 (A9)
/PA10: CART1.63 (PPU_A10), U1.5 (PPU_A10_(n))
/PA11: CART1.62 (PPU_A11), U1.4 (PPU_A11_(n))
/PA12: CART1.64 (PPU_A12), U1.3 (PPU_A12_(n))
/PA13: CART1.65 (PPU_A13), U3.24 (OE)
/PD0: CART1.30 (PPU_D0), U3.13 (D0)
/PD1: CART1.31 (PPU_D1), U3.14 (D1)
/PD2: CART1.32 (PPU_D2), U3.15 (D2)
/PD3: CART1.33 (PPU_D3), U3.17 (D3)
/PD4: CART1.69 (PPU_D4), U3.18 (D4)
/PD5: CART1.68 (PPU_D5), U3.19 (D5)
/PD6: CART1.67 (PPU_D6), U3.20 (D6)
/PD7: CART1.66 (PPU_D7), U3.21 (D7)
/Reset: CART1.70 (CIC_+RST), U4.7 (Rset)
/R/~W: CART1.14 (CPU_R/~W), U1.17 (R/W_(n))
/Xin: CART1.71 (CIC_CLK), U4.6 (Xin)
/~CE: U1.26 (PRG_~CE_(r)), U2.22 (CE)
/~IRQ: CART1.15 (~IRQ), U1.13 (~IRQ_(n))
/~RD: CART1.21 (PPU_~RD), U3.22 (CE)
/~ROMSEL: CART1.50 (~ROMSEL), U1.14 (~ROMSEL_(n))
GND: C1.2, C2.2, C3.2, CART1.1 (GND), CART1.72 (GND), JP1.1 (A), JP2.1 (A), U1.6 (GND), U1.15 (GND), U1.28 (GND), U1.40 (GND), U2.16 (GND), U2.24 (OE), U3.16 (GND), U4.3 (P0.2), U4.4 (P0.3), U4.8 (Gnd), U4.11 (P1.2), U4.12 (P1.3), U4.13 (P2.0), U4.14 (P2.1), U4.15 (P2.2)
unnamed: CART1.57 (CIRAM_~CE), CART1.58 (PPU_~A13)
unnamed: JP1.2 (C), U2.30 (A17)
unnamed: JP2.2 (C), U3.30 (A17)

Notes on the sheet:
128KB
PRG ROM
CHR ROM
256KB

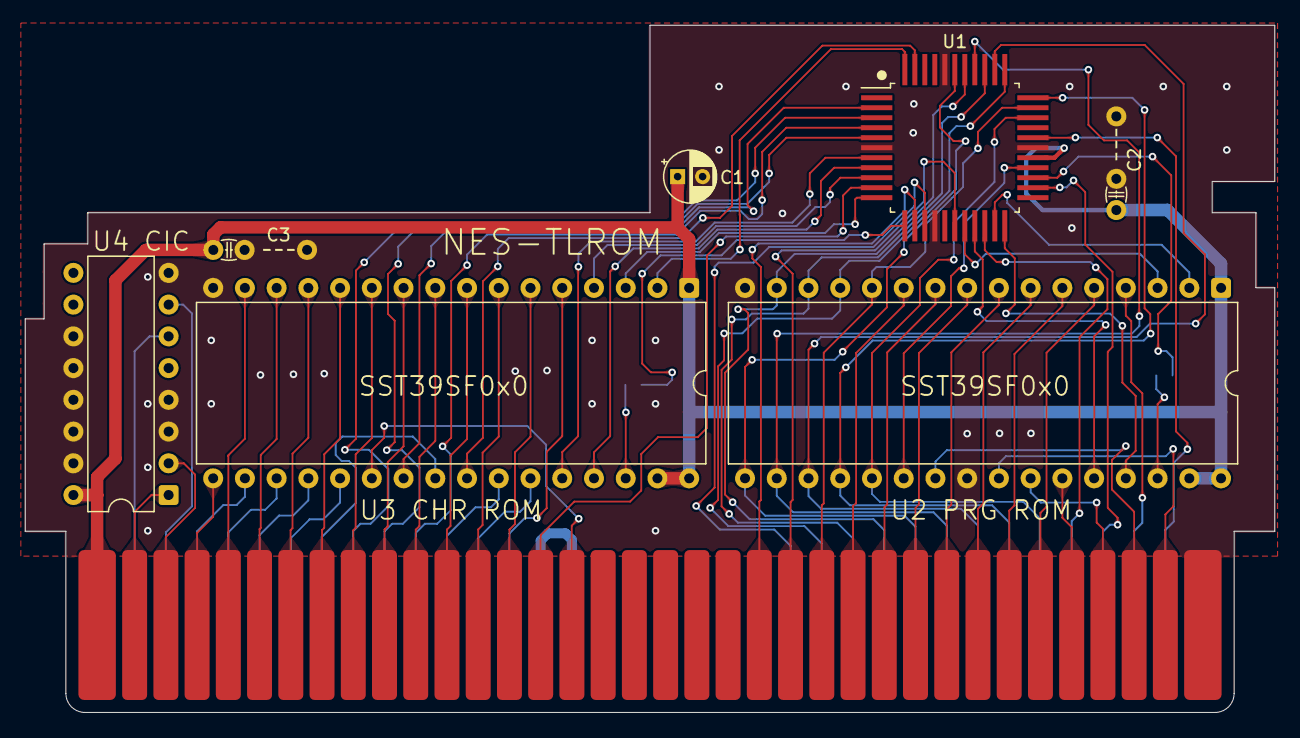
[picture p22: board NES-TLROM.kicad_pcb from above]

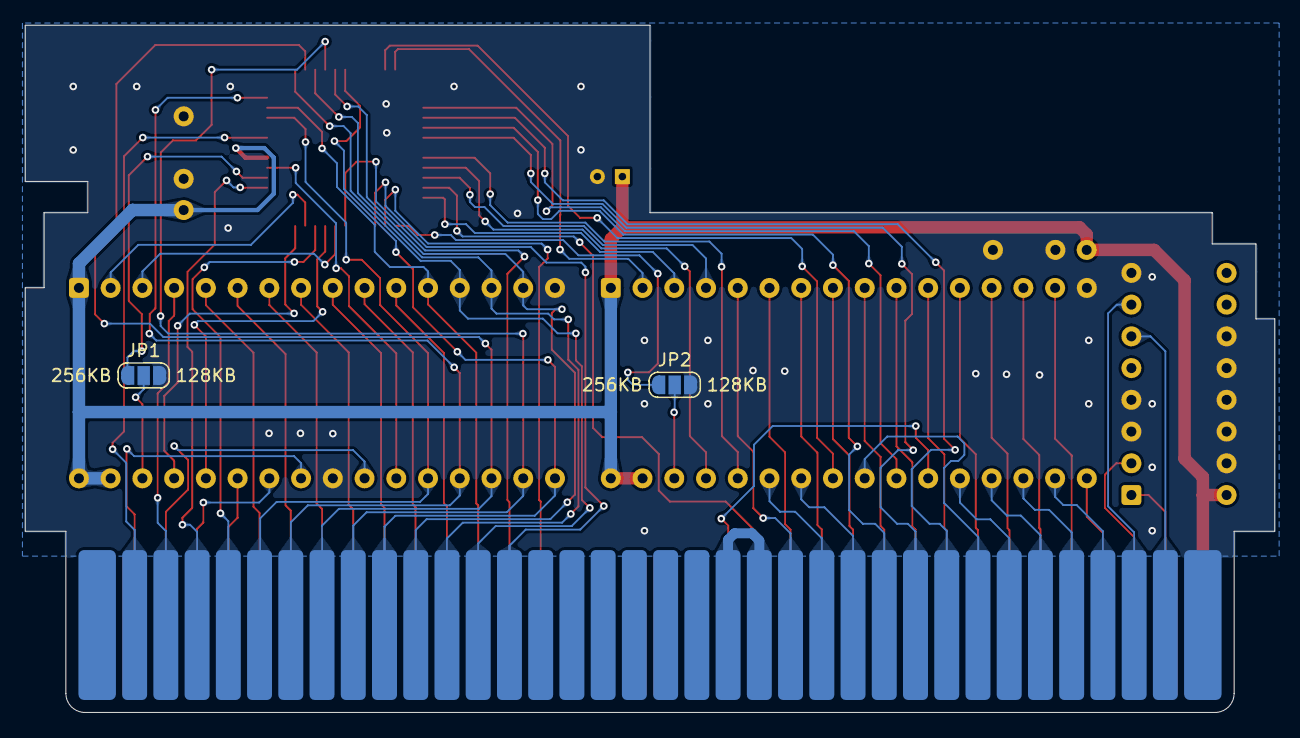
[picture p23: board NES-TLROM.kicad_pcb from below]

Board: 2 copper layers, 100.0 x 55.0 mm, 10 parts (2 on the bottom side), 74 nets.

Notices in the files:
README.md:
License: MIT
